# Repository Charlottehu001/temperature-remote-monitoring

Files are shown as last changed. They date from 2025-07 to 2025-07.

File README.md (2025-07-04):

# ESP32 MLX90640 Temperature Alarm System
[Chinese README](README_CH.md) | [English README](README.md)

## Project Overview

This project is an intelligent fire detection system based on the ESP32-C6 microcontroller and the MLX90640 infrared temperature sensor. The system integrates TinyML machine learning algorithms, multiple detection modes, real-time data visualization, and MQTT remote monitoring functions to provide accurate and reliable fire warnings.

### Key Features

- **High-Precision Temperature Detection**: Uses MLX90640 IR sensor with 32x24 pixel resolution
- **Machine Learning Detection**: Integrated TensorFlow Lite model for intelligent fire recognition
- **Multiple Detection Modes**: Supports threshold detection, ML-based detection, time integration, and hybrid modes
- **Real-Time Display**: 1.3" TFT color screen for thermal imaging and temperature display
- **Multi-Level Alarms**: LED indicators and buzzer alerts
- **MQTT Communication**: Remote monitoring and configuration support
- **Flexible Configuration**: 5 physical buttons for local parameter adjustments
- **Host Software**: Python PyQt5 desktop application for data monitoring

## Hardware Configuration

### Main Controller

- **MCU**: ESP32-C6 DevKitM-1
- **Sensor**: MLX90640-D55 IR temperature sensor array
- **Display**: 1.3" TFT ST7789 color display
- **LEDs**: 4 indicator LEDs
- **Buzzer**: Active buzzer
- **Buttons**: 5 function buttons

### Pin Mapping

#### MLX90640 Sensor (I2C)

| MLX90640 | ESP32-C6 |
|---|---|
| VCC 🔴 | 3V3 |
| GND ⚫ | GND |
| SDA ⚪ | GPIO2 |
| SCL 🟢 | GPIO3 |

#### TFT Display (SPI)

| TFT | ESP32-C6 |
|---|---|
| VCC 🔴 | 3V3 |
| GND ⚫ | GND |
| SCL 🟢 | GPIO21 |
| SDA ⚪ | GPIO19 |
| RES 🔁 | GPIO20 |
| DC 🟡 | GPIO22 |
| CS 🔷 | GPIO18 |

#### Other Peripherals

| Peripheral | Pin |
|---|---|
| Buzzer | GPIO15  |
| LED1 | GPIO10  |
| LED2 | GPIO11  |
| LED3 | GPIO12  |
| LED4 | GPIO13  |
| KEY1 | GPIO9 |
| KEY2 | GPIO4 |
| KEY3 | GPIO5 |
| KEY4 | GPIO6 |
| KEY5 | GPIO7 |

## Software Architecture

### Detection Modes

1. **Mode 1 - Traditional Threshold**: Based on max temperature threshold
2. **Mode 2 - ML Detection**: Fire recognition using TensorFlow Lite model
3. **Mode 3 - Time Integration**: Sliding window integration algorithm
4. **Mode 4 - Hybrid**: Combines ML and time integration for robust detection

### FreeRTOS Task Architecture

- **Display Task**: Handles TFT screen UI and image rendering
- **Detection Task**: Runs fire detection algorithms and peripheral control
- **Button Task**: Handles user input and parameter updates
- **MQTT Task**: Manages remote communication and config updates

### MQTT Communication Protocol

- **Data Reporting**: `/ESP32/detection_data` - Reports temperature and detection results
- **Config Receiving**: `/ESP32/config` - Receives config commands
- **Config Response**: `/ESP32/config_response` - Responds to config updates
- **Local Config Notification**: `/ESP32/config_update` - Reports local config changes

## Project Structure

```
esp32_mlx90640_temp_alert/
├── hardware/                    
│   ├── PCB.epro                
│   ├── Screen-structure.SLDDRW 
│   └── Screen-structure.SLDPRT 
├── software/
│   ├── esp32/                  
│   │   ├── project/            
│   │   │   ├── project_platformio/  
│   │   │   └── project_arduino/    
│   │   ├── component_test/     
│   │   └── tensorflow_lite_pio/ 
│   │       ├── 01.data_collection/
│   │       └── 04.run_model/      
│   └── mqtt_app/               
│       ├── main.py            
│       ├── ui/                
│       └── README.md          
├── README.md                   
├── README_CH.md               
└── .gitignore                 
```

## Installation and Usage

### Requirements

- **Development Environment**: PlatformIO IDE or Arduino IDE
- **Python Environment**: Python 3.x (for PC software)
- **Hardware**: ESP32-C6 board, MLX90640 sensor, TFT screen, etc.

### Firmware Build and Upload

1. Clone the repository
2. Use PlatformIO:
   - Open `software/esp32/project/project_platformio/main/main.ino`
   - Install required libraries
   - Select board: ESP32C6 Dev Module
   - Build and upload

3. Or use Arduino IDE:
   - Open `software/esp32/project/project_arduino/main/main.ino`
   - Install required libraries
   - Select board: ESP32C6 Dev Module
   - Build and upload

### Dependencies

- Adafruit MLX90640 - IR sensor driver
- Adafruit ST7789 - TFT display driver
- Adafruit GFX Library - Graphics library
- PubSubClient - MQTT client
- Chirale_TensorFLowLite - TensorFlow Lite support
- ArduinoJson - JSON parser

### PC Monitoring Software Setup

1. Navigate to the directory:

```
cd software/mqtt_app
```

2. Install dependencies (with uv package manager):

```
uv sync
```

3. Run the program:

```
uv run python main.py
```

## User Guide

### Button Functions

- KEY1: Toggle temperature range
- KEY2: Enter/exit settings
- KEY3: Select parameter in settings
- KEY4: Increase parameter value
- KEY5: Decrease parameter value

### Configurable Parameters

- Mode: Detection mode (1–4)
- Th1: Threshold 1 – traditional detection temperature (°C)
- Th2: Threshold 2 – ML confidence (0–1)
- Th3: Threshold 3 – time-integrated temperature (°C)
- Th4: Threshold 4 – hybrid mode confidence (0–1)
- Th5: Threshold 5 – fire frame ratio in hybrid mode (%)

### Status Indicators

- LEDs: All on when fire is detected; off in normal state
- Buzzer: Alarms on fire; short beep on key press
- TFT Display: Real-time thermal image and temperatures

## Development & Debugging

### Serial Debugging

- Baud rate: 115200
- Real-time output of temperatures and results
- System status and error logs

### Data Collection

Use code under `software/esp32/tensorflow_lite_pio/01.data_collection/` to collect training data.

### Model Training

The collected data can be used to train a custom fire detection model, convert it to TensorFlow Lite, and deploy it to the device.

## License

This project is licensed mainly under the Apache License 2.0.

- All original code and modifications: Apache License 2.0
- Third-party libraries retain their original licenses
- Some code references open-source MIT projects

See LICENSE file in the root directory for more details.

## Contributing

Feel free to submit Issues and Pull Requests to improve the project.

## Contact

If you have questions or suggestions, please open an Issue on GitHub.

> ⚠️ This system is for research and learning purposes only. Please fully test and validate it before using in real applications.

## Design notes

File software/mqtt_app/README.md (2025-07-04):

# Application Layer Software Deployment Guide

This application layer software is a desktop application developed based on Python and PyQt5, designed for real-time monitoring, data visualization, and historical record queries.

## Deployment Steps

1.  **Environment Preparation and Dependency Installation**

    First, please ensure that Python 3.x environment is installed on your computer. Then, you need to install the required dependency libraries for this application, mainly including `paho-mqtt`, `PyQt5`, and `pyqtgraph`. You can install these libraries through package management tools (such as pip).

2.  **UI File Conversion**

    The graphical user interface of this application is designed using Qt Designer, with source files in `.ui` format. Before running the main program, you need to convert this `.ui` file to Python code. This can be accomplished through the `pyuic5` tool, which will convert the `ui/Main.ui` file to `ui/Ui_Main.py`.

3.  **Run the Program**

    After completing the above preparations, you can directly run the `main.py` file to start the application.

## Function Verification

After the program starts, you can perform the following operations to verify its functionality:

*   **Connection Configuration**: In the "Connection/Debug" tab, enter your MQTT Broker's address, port, and client ID, then click the "Connect" button to establish a connection with the server.
*   **Data Display**: After successful connection, switch to the "Info/Control" tab, where you will see real-time updated temperature data (minimum, maximum, center temperature) and fire status indicator lights.
*   **Real-time Charts**: The charts at the bottom of this page will display temperature data change curves in real-time, helping you intuitively understand temperature trends.
*   **Historical Records**: In the "Record" tab, you can view detailed records of all historical fire events. These records support sorting by ID and can be exported as CSV files for further analysis.
*   **Message Debugging**: If debugging is needed, the "Connection/Debug" tab will display all received raw MQTT messages and allow you to manually publish messages to specified topics.

Through the above steps, you can successfully deploy and run this application layer software, achieving comprehensive monitoring and management of the fire alarm system.

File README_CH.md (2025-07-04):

# ESP32 MLX90640 温度报警系统
[中文版 README](README_CH.md) | [English README](README.md)
## 项目概述

本项目是一个基于ESP32-C6微控制器和MLX90640红外温度传感器的智能火灾检测系统。系统集成了TinyML机器学习算法、多种检测模式、实时数据可视化和MQTT远程监控功能，能够提供准确可靠的火灾预警。

### 主要特性

- **高精度温度检测**: 使用MLX90640红外传感器，32x24像素分辨率
-  **机器学习检测**: 集成TensorFlow Lite模型进行智能火灾识别
-  **多种检测模式**: 支持阈值检测、机器学习、时间积分和综合学习四种模式
-  **实时显示**: 1.3寸TFT彩屏显示热成像和温度数据
-  **多重报警**: LED指示灯、蜂鸣器声音报警
-  **MQTT通信**: 支持远程监控和配置管理
- **灵活配置**: 5个按键支持现场参数调节
-  **上位机软件**: Python PyQt5桌面应用程序用于数据监控

## 硬件配置

### 主控制器
- **MCU**: ESP32-C6 DevKitM-1
- **传感器**: MLX90640-D55 红外温度传感器阵列
- **显示屏**: 1.3寸 TFT ST7789 彩色显示屏
- **指示灯**: 4个LED指示灯
- **蜂鸣器**: 有源蜂鸣器
- **按键**: 5个功能按键

### 引脚连接

#### MLX90640传感器 (I2C接口)
| MLX90640 | ESP32-C6 |
|---|---|
| VCC 🔴   | 3V3      |
| GND ⚫   | GND      |
| SDA ⚪   | GPIO2    |
| SCL 🟢   | GPIO3    |

#### TFT显示屏 (SPI接口)
| TFT屏幕 | ESP32-C6 |
|---|---|
| VCC 🔴  | 3V3      |
| GND ⚫  | GND      |
| SCL 🟢  | GPIO21   |
| SDA ⚪  | GPIO19   |
| RES 🔁  | GPIO20   |
| DC 🟡   | GPIO22   |
| CS 🔷   | GPIO18   |

#### 其他外设
| 外设 | 引脚 |
|---|---|
| 蜂鸣器 | GPIO15 |
| LED1 | GPIO10 |
| LED2 | GPIO11 |
| LED3 | GPIO12 |
| LED4 | GPIO13 |
| KEY1 | GPIO9 |
| KEY2 | GPIO4 |
| KEY3 | GPIO5 |
| KEY4 | GPIO6 |
| KEY5 | GPIO7 |

## 软件架构

### 检测模式

1. **模式1 - 传统阈值检测**: 基于最高温度阈值判断
2. **模式2 - 机器学习检测**: 使用TensorFlow 
Lite模型进行智能识别
3. **模式3 - 时间积分检测**: 滑动窗口时间积分算法
4. **模式4 - 综合学习检测**: 机器学习结合时间积分
的混合模式

### FreeRTOS任务架构

- **显示任务**: 负责TFT屏幕显示和用户界面
- **检测处理任务**: 执行火灾检测算法和外设控制
- **按键处理任务**: 处理用户输入和参数调节
- **MQTT通信任务**: 处理远程通信和配置更新

### MQTT通信协议

- **数据上报**: `/ESP32/detection_data` - 温度数据和检测结果
- **配置接收**: `/ESP32/config` - 接收远程配置命令
- **配置响应**: `/ESP32/config_response` - 配置确认消息
- **配置更新**: `/ESP32/config_update` - 本地配置变更通知

## 项目结构

```
esp32_mlx90640_temp_alert/
├── hardware/                    # 硬件设计文件
│   ├── PCB.epro                # PCB设计文件
│   ├── Screen-structure.SLDDRW # 屏幕结构图
│   └── Screen-structure.SLDPRT # 屏幕结构3D模型
├── software/
│   ├── esp32/                  # ESP32固件代码
│   │   ├── project/            # 主项目代码
│   │   │   ├── project_patformio/  # PlatformIO版本
│   │   │   └── project_arduino/    # Arduino IDE版本
│   │   ├── component_test/     # 组件测试代码
│   │   └── tensorflow_lite_pio/ # TensorFlow Lite相关
│   │       ├── 01.data_collection/ # 数据收集
│   │       └── 04.run_model/      # 模型运行
│   └── mqtt_app/               # 上位机监控软件
│       ├── main.py            # 主程序
│       ├── ui/                # 用户界面
│       └── README.md          # 部署说明
├── README.md                   # 英文说明文档
├── README_CH.md               # 中文说明文档
└── .gitignore                 # Git忽略文件

```

## 安装和使用

### 环境要求

- **开发环境**: PlatformIO IDE 或 Arduino IDE
- **Python环境**: Python 3.x (用于上位机软件)
- **硬件**: ESP32-C6开发板、MLX90640传感器、TFT
显示屏等

### 固件编译和烧录

1. 克隆项目:
2. 使用PlatformIO编译 :
   - 打开 software/esp32/project/project_platformio/main/main.ino
   - 安装所需库文件
   - 选择开发板: ESP32C6 Dev Module
   - 编译并上传
3. 或使用Arduino IDE :
   - 打开 software/esp32/project/project_arduino/main/main.ino
   - 安装所需库文件
   - 选择开发板: ESP32C6 Dev Module
   - 编译并上传
### 依赖库
- Adafruit MLX90640 - MLX90640传感器驱动
- Adafruit ST7789 - TFT显示屏驱动
- Adafruit GFX Library - 图形库
- PubSubClient - MQTT客户端
- Chirale_TensorFLowLite - TensorFlow Lite支持
- ArduinoJson - JSON数据处理
### 上位机软件部署
1. 进入软件目录 :
   
   ```
   cd software/mqtt_app
   ```
2. 安装依赖 (使用uv包管理器):
   
   ```
   uv sync
   ```
3. 运行程序 :
   
   ```
   uv run python main.py
   ```
## 使用说明
### 按键功能
- KEY1 : 切换温度显示范围
- KEY2 : 进入/退出设置模式
- KEY3 : 在设置模式下选择参数项
- KEY4 : 增加参数值
- KEY5 : 减少参数值
### 设置参数

- Mode : 检测模式 (1-4)
- Th1 : 阈值1 - 传统检测温度阈值 (°C)
- Th2 : 阈值2 - 机器学习置信度阈值 (0-1)
- Th3 : 阈值3 - 时间积分温度阈值 (°C)
- Th4 : 阈值4 - 综合模式置信度阈值 (0-1)
- Th5 : 阈值5 - 综合模式火灾帧比例阈值 (%)
### 状态指示
- LED指示灯 : 火灾检测时全部点亮，正常时熄灭
- 蜂鸣器 : 火灾报警时鸣响，按键操作时短鸣
- TFT显示 : 实时热成像显示和温度数值
## 开发和调试
### 串口调试
- 波特率: 115200
- 实时输出温度数据和检测结果
- 系统状态和错误信息
### 数据收集
使用 software/esp32/tensorflow_lite_pio/01.data_collection/ 中的代码进行训练数据收集。

### 模型训练
收集的数据可用于训练自定义的火灾检测模型，然后转换为TensorFlow Lite格式部署到设备上。

## 许可证
本项目主要采用Apache License 2.0许可证。

- 所有原创代码和修改内容均采用Apache License 2.0许可证
- 第三方库和组件保持其原有许可证
- 部分代码参考了MIT许可证的开源项目
详细信息请参阅项目根目录下的LICENSE文件。

## 贡献
欢迎提交Issue和Pull Request来改进项目。

## 联系方式
如有问题或建议，请在GitHub仓库中创建Issue。

注意 : 本系统仅用于研究和学习目的，在实际应用中请根据具体环境进行充分测试和验证。

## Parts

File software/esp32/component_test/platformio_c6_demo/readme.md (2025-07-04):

# 在PIO使用新版的arduino平台
由于一些原因platformio并未支持[Arduino ESP32](https://github.com/espressif/arduino-esp32)到 3.0以上
>详情见:
>https://github.com/platformio/platform-espressif32/issues/1225

于是我们可以手动引包，并指定相关开发板配置的来支持Arduino ESP32 3.0开发。

## 注意
* 这里依然不能新建项目，需要复制platformio.ini到新的文件夹。
接下来打开项目

    1.使用`platformio.exe init --ide vscode` 初始化项目，然后使用vscode打开。

    2.或者使用clion打开项目时候自动同步platformio.ini。

**由于一些openocd 配置问题暂未解决，暂时无法使用该方法debug**

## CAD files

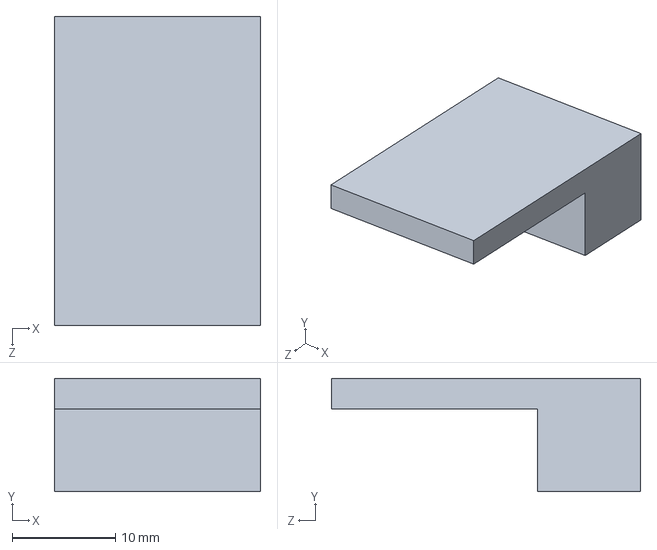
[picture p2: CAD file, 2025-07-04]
hardware/Screen-structure.SLDPRT
20.0 x 11.0 x 30.0 mm

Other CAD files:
hardware/Screen-structure.SLDDRW

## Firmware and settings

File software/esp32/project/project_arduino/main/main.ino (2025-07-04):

#include "main.h"
#include <ArduinoJson.h>

#define MLX_ADDR 0x33
#define I2C_HZ 400000

Adafruit_ST7789 tft = Adafruit_ST7789(TFT_CS, TFT_DC, TFT_RST);
constexpr mlx90640_refreshrate_t FPS = MLX90640_16_HZ;
Adafruit_MLX90640 mlx;

// Temperature range definition
typedef struct
{
  int minTemp;
  int maxTemp;
} TempRange;

// Temperature range groups (determines display effect)
TempRange tempRanges[] = {
    {20, 36},
    {25, 40},
    {15, 30}};
volatile int currentRangeIndex = 0; // Currently selected temperature range group

// Inference library configuration
constexpr int kTensorArenaSize = 35000; // Increase appropriately according to model
alignas(16) uint8_t tensor_arena[kTensorArenaSize];

// TFLite component pointers
const tflite::Model *model = nullptr;
tflite::MicroInterpreter *interpreter = nullptr;
TfLiteTensor *input = nullptr;
TfLiteTensor *output = nullptr;

// Configuration update flag
volatile bool configUpdatePending = false;

typedef struct
{
  bool setting;         // Whether in setting mode
  int selectedItem;     // Currently selected setting item
  int measurement_mode; // Measurement mode: 1: Threshold method, 2: Machine learning method, 3: Time integration method, 4: Comprehensive learning method
  float threshold_1;
  float threshold_2;
  float threshold_3;
  float threshold_4;
  float threshold_5;
} SystemSettings;

// Specific settings
SystemSettings sysConfig = {
    .setting = false,
    .selectedItem = 0,
    .measurement_mode = 1,
    .threshold_1 = 45,
    .threshold_2 = 0.7,
    .threshold_3 = 45,
    .threshold_4 = 0.7,
    .threshold_5 = 70};

// Key structure
typedef struct
{
  uint8_t pin;
  bool pressed;
  void (*onPressed)(); // Callback function when pressed
} Key;

void onKey1Pressed()
{
  Serial.println("KEY1 pressed!");
  currentRangeIndex++;
  if (currentRangeIndex >= (sizeof(tempRanges) / sizeof(tempRanges[0])))
    currentRangeIndex = 0;
  Serial.print("Switch to temperature range group: ");
  Serial.println(currentRangeIndex);
}

void onKey2Pressed()
{
  Serial.println("KEY2 pressed! (can add functionality)");
  // Switch setting mode
  if (sysConfig.setting)
  {
    sysConfig.setting = false;
    Serial.println("Exited setting mode");
  }
  else
  {
    sysConfig.setting = true;
    Serial.println("Entered setting mode");
  }
}

void onKey3Pressed()
{
  Serial.println("KEY3 pressed! (adjustment mode)");
  sysConfig.selectedItem++;
  if (sysConfig.selectedItem > 5)
  {
    sysConfig.selectedItem = 0;
  }
}

void onKey4Pressed()
{
  switch (sysConfig.selectedItem)
  {
  case 0:
    sysConfig.measurement_mode++;
    if (sysConfig.measurement_mode > 4)
    {
      sysConfig.measurement_mode = 1;
    }
    break;
  case 1:
    sysConfig.threshold_1 = sysConfig.threshold_1 + 10;
    if (sysConfig.threshold_1 > 150)
    {
      sysConfig.threshold_1 = 0;
    }
    break;
  case 2:
    sysConfig.threshold_2 = sysConfig.threshold_2 + 0.1;
    if (sysConfig.threshold_2 > 1)
    {
      sysConfig.threshold_2 = 0;
    }
    break;
  case 3:
    sysConfig.threshold_3 = sysConfig.threshold_3 + 10;
    if (sysConfig.threshold_3 > 100)
    {
      sysConfig.threshold_3 = 0;
    }
    break;
  case 4:
    sysConfig.threshold_4 = sysConfig.threshold_4 + 0.1;
    if (sysConfig.threshold_4 > 1)
    {
      sysConfig.threshold_4 = 0;
    }
    break;
  case 5:
    sysConfig.threshold_5 = sysConfig.threshold_5 + 10;
    if (sysConfig.threshold_5 > 100)
    {
      sysConfig.threshold_5 = 0;
    }
    break;
  default:
    break;
  }
  
  // Mark that configuration update needs to be sent (delayed to task execution)
  configUpdatePending = true;
}

void onKey5Pressed()
{
  switch (sysConfig.selectedItem)
  {
  case 0:
    sysConfig.measurement_mode--;
    if (sysConfig.measurement_mode < 1)
    {
      sysConfig.measurement_mode = 4;
    }
    break;
  case 1:
    sysConfig.threshold_1 -= 10;
    if (sysConfig.threshold_1 < 0)
    {
      sysConfig.threshold_1 = 150;
    }
    break;
  case 2:
    sysConfig.threshold_2 -= 0.1;
    if (sysConfig.threshold_2 < 0)
    {
      sysConfig.threshold_2 = 1.0;
    }
    break;
  case 3:
    sysConfig.threshold_3 -= 10;
    if (sysConfig.threshold_3 < 0)
    {
      sysConfig.threshold_3 = 100;
    }
    break;
  case 4:
    sysConfig.threshold_4 -= 0.1;
    if (sysConfig.threshold_4 < 0)
    {
      sysConfig.threshold_4 =  1.0;
    }
    break;
  case 5:
    sysConfig.threshold_5 -= 10;
    if (sysConfig.threshold_5 < 0)
    {
      sysConfig.threshold_5 = 100;
    }
    break;
  default:
    break;
  }
  
  // Mark that configuration update needs to be sent (delayed to task execution)
  configUpdatePending = true;
}

// Instantiate keys
Key keys[] = {
    {KEY1_PIN, false, onKey1Pressed},
    {KEY2_PIN, false, onKey2Pressed},
    {KEY3_PIN, false, onKey3Pressed},
    {KEY4_PIN, false, onKey4Pressed},
    {KEY5_PIN, false, onKey5Pressed}};
const uint8_t keyCount = sizeof(keys) / sizeof(keys[0]);

// Frame data structure
typedef struct
{
  float frame[32 * 24];
  float tMin;
  float tMax;
  float tCenter;
} FrameData;

// Queue handles
QueueHandle_t displayQueue;
QueueHandle_t disposalQueue;



// MQTT message processing callback function
void onMQTTMessage(char* topic, byte* payload, unsigned int length)
{
  // Convert payload to string
  char message[length + 1];
  memcpy(message, payload, length);
  message[length] = '\0';
  
  Serial.print("Received MQTT message [Topic: ");
  Serial.print(topic);
  Serial.print("] Content: ");
  Serial.println(message);
  
  // Parse JSON message
  DynamicJsonDocument doc(1024);
  DeserializationError error = deserializeJson(doc, message);
  
  if (error) {
    Serial.print("JSON parsing failed: ");
    Serial.println(error.c_str());
    return;
  }
  
  // Update system configuration
  if (doc.containsKey("measurement_mode")) {
    int mode = doc["measurement_mode"];
    if (mode >= 1 && mode <= 4) {
      sysConfig.measurement_mode = mode;
      Serial.print("Update measurement mode: ");
      Serial.println(mode);
    }
  }
  
  if (doc.containsKey("threshold_1")) {
    float th1 = doc["threshold_1"];
    if (th1 >= 0 && th1 <= 150) {
      sysConfig.threshold_1 = th1;
      Serial.print("Update threshold 1: ");
      Serial.println(th1);
    }
  }
  
  if (doc.containsKey("threshold_2")) {
    float th2 = doc["threshold_2"];
    if (th2 >= 0 && th2 <= 1.0) {
      sysConfig.threshold_2 = th2;
      Serial.print("Update threshold 2: ");
      Serial.println(th2);
    }
  }
  
  if (doc.containsKey("threshold_3")) {
    float th3 = doc["threshold_3"];
    if (th3 >= 0 && th3 <= 100) {
      sysConfig.threshold_3 = th3;
      Serial.print("Update threshold 3: ");
      Serial.println(th3);
    }
  }
  
  if (doc.containsKey("threshold_4")) {
    float th4 = doc["threshold_4"];
    if (th4 >= 0 && th4 <= 1.0) {
      sysConfig.threshold_4 = th4;
      Serial.print("Update threshold 4: ");
      Serial.println(th4);
    }
  }
  
  if (doc.containsKey("threshold_5")) {
    float th5 = doc["threshold_5"];
    if (th5 >= 0 && th5 <= 100) {
      sysConfig.threshold_5 = th5;
      Serial.print("Update threshold 5: ");
      Serial.println(th5);
    }
  }
  
  // Send confirmation message
  char confirmMsg[256];
  snprintf(confirmMsg, sizeof(confirmMsg), 
           "{\"status\":\"ok\",\"mode\":%d,\"th1\":%.1f,\"th2\":%.2f,\"th3\":%.1f,\"th4\":%.2f,\"th5\":%.1f}",
           sysConfig.measurement_mode, sysConfig.threshold_1, sysConfig.threshold_2, 
           sysConfig.threshold_3, sysConfig.threshold_4, sysConfig.threshold_5);
  sendMQTTMessage("/ESP32/config_response", confirmMsg);
}

// -------------------- Task Definitions -------------------------

// Model inference initialization
void TFLite_init()
{
  Serial.println("Initializing TFLite Micro...");
  model = tflite::GetModel(g_model);
  if (model->version() != TFLITE_SCHEMA_VERSION)
  {
    Serial.println("Model version incompatible with library!");
    while (1)
      ;
  }

  static tflite::AllOpsResolver resolver;
  static tflite::MicroInterpreter static_interpreter(model, resolver, tensor_arena, kTensorArenaSize);
  interpreter = &static_interpreter;

  if (interpreter->AllocateTensors() != kTfLiteOk)
  {
    Serial.println("Tensor memory allocation failed!");
    while (1)
      ;
  }

  input = interpreter->input(0);
  output = interpreter->output(0);
}

// Display task
void Task_Display(void *pvParameters)
{
  (void)pvParameters;
  FrameData frameData;
  int displayPixelWidth = 8;
  int displayPixelHeight = 8;

  static bool settingLastState = false; // Whether it was in setting state last time

  while (1)
  {
    bool settingNow = sysConfig.setting;

    if (settingNow)
    {
      // If entering setting mode for the first time, clear screen + display title
      if (!settingLastState)
      {
        tft.fillScreen(ST77XX_BLACK);
        tft.setTextSize(2);
        tft.setTextColor(ST77XX_WHITE);
        tft.setCursor(10, 10);
        tft.print("== SETTINGS ==");
      }

      // Highlight color definition
      uint16_t highlightColor = ST77XX_YELLOW;
      uint16_t normalColor = ST77XX_WHITE;

      // Menu items
      String items[] = {
          "Mode: " + String(sysConfig.measurement_mode),
          "Th1: " + String(sysConfig.threshold_1, 1),
          "Th2: " + String(sysConfig.threshold_2, 1),
          "Th3: " + String(sysConfig.threshold_3, 1),
          "Th4: " + String(sysConfig.threshold_4, 1),
          "Th5: " + String(sysConfig.threshold_5, 1)};

      for (int i = 0; i < 6; i++)
      {
        int y = 40 + i * 30;
        // Only update changed content (can be further optimized)
        tft.fillRect(5, y - 2, 230, 24, ST77XX_BLACK);
        tft.setTextColor(i == sysConfig.selectedItem ? highlightColor : normalColor);
        tft.setCursor(10, y);
        tft.print(items[i]);
      }

      delay(1); // Reduce refresh tearing
    }
    else if (xQueueReceive(displayQueue, &frameData, portMAX_DELAY) == pdPASS)
    {
      float tMinSet = tempRanges[currentRangeIndex].minTemp;
      float tMaxSet = tempRanges[currentRangeIndex].maxTemp;

      for (uint8_t h = 0; h < 24; h++)
      {
        for (uint8_t w = 0; w < 32; w++)
        {
          float t = frameData.frame[h * 32 + w];
          t = min(t, tMaxSet);
          t = max(t, tMinSet);
          uint8_t colorIndex = map(t, tMinSet, tMaxSet, 0, 255);
          colorIndex = constrain(colorIndex, 0, 255);
          tft.fillRect(w * displayPixelWidth, h * displayPixelHeight,
                       displayPixelWidth, displayPixelHeight, camColors[colorIndex]);
        }
      }

      // Display temperature values
      if (!settingNow)
      {
        tft.fillRect(0, 192, 240, 48, ST77XX_BLACK);

        tft.setCursor(10, 200);
        tft.setTextColor(ST77XX_WHITE);
        tft.setTextSize(2);
        tft.print("Max:");
        tft.print(frameData.tMax, 1);

        tft.setCursor(120, 200);
        tft.print("Min:");
        tft.print(frameData.tMin, 1);

        tft.setCursor(10, 220);
        tft.print("Center: ");
        tft.print(frameData.tCenter, 1);
      }
    }

    // Update status flag
    settingLastState = settingNow;
  }
}

// Detection processing task
void Task_Disposal(void *pvParameters)
{
  (void)pvParameters;
  FrameData frameData;

  while (1)
  {
    if (xQueueReceive(disposalQueue, &frameData, portMAX_DELAY) == pdPASS)
    {
      bool fireDetected = false; // Whether fire is detected

      switch (sysConfig.measurement_mode)
      {
      case 1: // Mode 1: Traditional threshold detection
        if (frameData.tMax >= sysConfig.threshold_1)
        {
          fireDetected = true;
        }
        break;

      case 2: // Mode 2: ML inference detection
      {
        // Fill input tensor (int8)
        for (int i = 0; i < 768; i++)
        {
          float val = frameData.frame[i];
          int8_t q = (int8_t)(roundf(val / input->params.scale) + input->params.zero_point);
          input->data.int8[i] = q;
        }

        if (interpreter->Invoke() != kTfLiteOk)
        {
          Serial.println("Inference failed!");
          break;
        }

        int8_t result = output->data.int8[0];
        float score = (result - output->params.zero_point) * output->params.scale * 2;

        Serial.print("Score: ");
        Serial.println(score);

        if (score >= sysConfig.threshold_2)
        {
          fireDetected = true;
        }
        break;
      }

      case 3: // Mode 3: Sliding window integration detection
      {
        // Static variables to maintain sliding window
        static const int N = 10; // Window size
        static const int M = 6;  // Trigger condition (fire frame count)
        static bool ringBuffer[N] = {0};
        static int index = 0;
        static int fireCount = 0;

        // Determine if current frame is a "fire frame"
        bool currentIsFire = frameData.tMax >= sysConfig.threshold_3;

        // Update sliding window
        if (ringBuffer[index])
          fireCount--;                     // Subtract old value
        ringBuffer[index] = currentIsFire; // Write new value
        if (currentIsFire)
          fireCount++; // Add new value

        index = (index + 1) % N; // Circular update index

        // Check if fire alarm condition is met
        if (fireCount >= M)
        {
          fireDetected = true;
        }

        break;
      }

      case 4: // Mode 4: Machine learning with sliding window time integration
      {
        // First perform ML inference
        for (int i = 0; i < 768; i++)
        {
          float val = frameData.frame[i];
          int8_t q = (int8_t)(roundf(val / input->params.scale) + input->params.zero_point);
          input->data.int8[i] = q;
        }

        if (interpreter->Invoke() != kTfLiteOk)
        {
          Serial.println("Inference failed!");
          break;
        }

        int8_t result = output->data.int8[0];
        float score = (result - output->params.zero_point) * output->params.scale * 2;

        Serial.print("Score: ");
        Serial.println(score);

        // Static variables to maintain sliding window
        static const int N = 10; // Window size
        static bool ringBuffer[N] = {0};
        static int index = 0;
        static int fireCount = 0;

        // Determine if current frame is a "fire frame" (based on ML score)
        bool currentIsFire = score >= sysConfig.threshold_4;

        // Update sliding window
        if (ringBuffer[index])
          fireCount--;                     // Subtract old value
        ringBuffer[index] = currentIsFire; // Write new value
        if (currentIsFire)
          fireCount++; // Add new value

        index = (index + 1) % N; // Circular update index

        // Calculate fire frame ratio and compare with threshold
        float fireRatio = (float)fireCount / N * 100.0; // Calculate fire frame ratio (percentage)
        if (fireRatio >= sysConfig.threshold_5)
        {
          fireDetected = true;
        }
        break;
      }

      default:
        Serial.println("Unknown measurement mode");
        break;
      }

      // Send detection result data (send regardless of whether fire is detected)
      char dataMsg[256];
      snprintf(dataMsg, sizeof(dataMsg),
               "{\"tMin\":%.1f,\"tMax\":%.1f,\"tCenter\":%.1f,\"fireDetected\":%d}",
               frameData.tMin, frameData.tMax, frameData.tCenter, fireDetected ? 1 : 0);
      sendMQTTMessage("/ESP32/detection_data", dataMsg);

      // Control peripherals based on fireDetected
      if (fireDetected)
      {
        Serial.println("🔥 Fire detected");
        buzzer_on();
        led_on(0);
        led_on(1);
        led_on(2);
      }
      else
      {
        Serial.println("✅ No fire");
        buzzer_off();
        led_off(0);
        led_off(1);
        led_off(2);
      }
    }
  }
}

// Key scanning task
void Task_KeyProcess(void *pvParameters)
{
  (void)pvParameters;
  for (uint8_t i = 0; i < keyCount; ++i)
    pinMode(keys[i].pin, INPUT_PULLUP);

  while (1)
  {
    for (uint8_t i = 0; i < keyCount; ++i)
    {
      static bool lastState[10] = {true}; // Support up to 10 buttons
      bool currentState = digitalRead(keys[i].pin);

      // Detected button press (falling edge)
      if (lastState[i] && !currentState)
      {
        buzzer_beep(1);
        keys[i].pressed = true;
        if (keys[i].onPressed)
          keys[i].onPressed();
      }

      lastState[i] = currentState;
    }
    vTaskDelay(pdMS_TO_TICKS(10)); // Scan interval
  }
}

// MQTT message receiving task
void Task_MQTTReceive(void *pvParameters)
{
  (void)pvParameters;
  
  while (1)
  {
    mqttLoop(); // Process MQTT messages
    
    // Check if configuration update needs to be sent
    if (configUpdatePending)
    {
      configUpdatePending = false;
      
      // Send configuration update to MQTT
      char configMsg[256];
      snprintf(configMsg, sizeof(configMsg), 
               "{\"measurement_mode\":%d,\"threshold_1\":%.1f,\"threshold_2\":%.2f,\"threshold_3\":%.1f,\"threshold_4\":%.2f,\"threshold_5\":%.1f}",
               sysConfig.measurement_mode, sysConfig.threshold_1, sysConfig.threshold_2, 
               sysConfig.threshold_3, sysConfig.threshold_4, sysConfig.threshold_5);
      sendMQTTMessage("/ESP32/config_update", configMsg);
      Serial.println("Configuration uploaded via MQTT");
    }
    
    vTaskDelay(pdMS_TO_TICKS(50)); // 50ms interval
  }
}

// -------------------- System Initialization -------------------------

// Generic screen initialization progress display function
void displayInitProgress(const char* message, bool success = true)
{
  static int lineCount = 0;
  static bool screenCleared = false;
  
  // Clear screen and display title on first call
  if (!screenCleared) {
    tft.fillScreen(ST77XX_BLACK);
    tft.setTextSize(2);
    tft.setTextColor(ST77XX_WHITE);
    tft.setCursor(10, 10);
    tft.print("System Init...");
    tft.drawLine(10, 35, 230, 35, ST77XX_WHITE);
    lineCount = 0;
    screenCleared = true;
  }
  
  // Calculate display position
  int y = 50 + lineCount * 20;
  
  // If exceeding screen range, scroll display
  if (y > 220) {
    // Scroll up
    tft.fillRect(10, 50, 220, 170, ST77XX_BLACK);
    lineCount = 0;
    y = 50;
  }
  
  // Set text attributes
  tft.setTextSize(1);
  tft.setTextColor(success ? ST77XX_GREEN : ST77XX_RED);
  tft.setCursor(10, y);
  
  // Display message
  tft.print(success ? "[OK] " : "[ERR] ");
  tft.print(message);
  
  lineCount++;
  
  // Brief delay to let user see progress
  delay(10);
}
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
void loop()
{
  static uint32_t lastTime = 0;
  uint32_t timestamp = millis();

  FrameData frameData;

  // Collect data
  if (mlx.getFrame(frameData.frame) != 0)
  {
    Serial.println(F("Read failed, skip this frame"));
    delay(10);
    return;
  }

  // Data preprocessing (calculate mean, center point)
  frameData.tMin = frameData.frame[0];
  frameData.tMax = frameData.frame[0];
  for (uint16_t i = 1; i < 768; ++i)
  {
    if (frameData.frame[i] < frameData.tMin)
      frameData.tMin = frameData.frame[i];
    if (frameData.frame[i] > frameData.tMax)
      frameData.tMax = frameData.frame[i];
  }
  frameData.tCenter = frameData.frame[12 * 32 + 16];

  // Send data frame to queues
  xQueueSend(displayQueue, &frameData, portMAX_DELAY);
  xQueueSend(disposalQueue, &frameData, portMAX_DELAY);

  uint32_t now = millis();
  uint32_t frameTime = now - lastTime;
  lastTime = now;

  Serial.print(F("Frame collection time: "));
  Serial.print(frameTime);
  Serial.println(F(" ms"));
}

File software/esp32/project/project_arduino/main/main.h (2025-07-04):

#ifndef MAIN_H
#define MAIN_H

/*********************************************************
	MLX90640-D55 + ESP32-C6 DevKitM-1 + 1.3 TFT ST7789
	Function: Real-time serial output & TFT display
	▸ MLX90640 (I2C interface):
	│ VCC 🔴      │ → 3V3
	│ GND ⚫      │ → GND
	│ SDA ⚪      │ → GPIO11   (c3: 8)
	│ SCL 🟢      │ → GPIO10   (c3: 7)

	▸ OLED Screen (SPI interface):
	│ VCC 🔴      │ → 3V3
	│ GND ⚫      │ → GND
	│ SCL 🟢      │ → GPIO21 (SPI CLK) (c3: 4)(cannot be changed)
	│ SDA ⚪      │ → GPIO19 (SPI MOSI)(c3: 6)(cannot be changed)
	│ RES 🔁      │ → GPIO4 (c3: 12)
	│ DC  🟡      │ → GPIO5 (c3: 18)
	│ CS  🔷      │ → (not connected)
	│ BLK ⚫      │ → (not connected)

*********************************************************/
#include <Adafruit_MLX90640.h>
#include <Adafruit_GFX.h>
#include <Adafruit_ST7789.h>
#include <SPI.h>
#include <Wire.h>
#include <Arduino.h>
#include "freertos/FreeRTOS.h"
#include "freertos/task.h"
#include "freertos/queue.h"
#include "cam_colors.h"
#include "wifi_mqtt.h"
#include "led.h"
#include "buzzer.h"
#include <Chirale_TensorFlowLite.h>
#include "model.h"
#include "tensorflow/lite/micro/all_ops_resolver.h"
#include "tensorflow/lite/micro/micro_interpreter.h"
#include "tensorflow/lite/schema/schema_generated.h"

// TFT pin definitions
#define TFT_CS  18
#define TFT_RST 20
#define TFT_DC  22
#define TFT_SDA 19  // (cannot be changed)
#define TFT_SCL 21	// (cannot be changed)

// MLX90640 configuration
#define SDA_PIN 2
#define SCL_PIN 3

// Buzzer pin
#define BUZZER_PIN 15

// LED pin definitions
#define LED1_PIN 10
#define LED2_PIN 11
#define LED3_PIN 12
#define LED4_PIN 13

// Button pins
#define KEY1_PIN 9
#define KEY2_PIN 4
#define KEY3_PIN 5
#define KEY4_PIN 6
#define KEY5_PIN 7



#endif

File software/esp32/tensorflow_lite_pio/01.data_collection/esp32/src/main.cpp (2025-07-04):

/*********************************************************
  MLX90640-D55 Data Collection Test Program (CSV Output with Labels)
*********************************************************/
#include <Wire.h>
#include <Adafruit_MLX90640.h>

/*========== Parameter Configuration ==========*/
#define LABEL 1 // Data label: 0 = no flame, 1 = flame detected

constexpr uint8_t SDA_PIN = 2;
constexpr uint8_t SCL_PIN = 3;
constexpr uint8_t MLX_ADDR = 0x33;
constexpr uint32_t I2C_HZ = 100000;
constexpr mlx90640_refreshrate_t FPS = MLX90640_2_HZ;
/*==========================================*/

Adafruit_MLX90640 mlx;
float frame[32 * 24];
bool headerPrinted = false;

void setup()
{
  Serial.begin(115200);
  delay(50);

  Wire.begin(SDA_PIN, SCL_PIN);
  Wire.setClock(I2C_HZ);

  Serial.println(F("\nMLX90640-D55 initializing..."));
  if (!mlx.begin(MLX_ADDR, &Wire))
  {
    Serial.println(F("ERROR: Sensor not found!"));
    while (true)
      delay(1000);
  }

  mlx.setMode(MLX90640_CHESS);
  mlx.setResolution(MLX90640_ADC_18BIT);
  mlx.setRefreshRate(FPS);

  Serial.println(F("Initialization complete, starting data collection..."));
}

void loop()
{
  if (mlx.getFrame(frame) != 0)
  {
    Serial.println(F("Read failed, skipping this frame"));
    delay(10);
    return;
  }

  // Print CSV header (only once)
  if (!headerPrinted)
  {
    Serial.print("label");
    for (int i = 0; i < 768; i++)
    {
      Serial.print(",p");
      Serial.print(i);
    }
    Serial.println();
    headerPrinted = true;
  }

  // Print one frame of data (first column is label)
  Serial.print(LABEL);
  for (int i = 0; i < 768; i++)
  {
    Serial.print(",");
    Serial.print(frame[i], 2); // Keep 2 decimal places
  }
  Serial.println();

  delay(500); // Control sampling frequency (one frame per second)
}
